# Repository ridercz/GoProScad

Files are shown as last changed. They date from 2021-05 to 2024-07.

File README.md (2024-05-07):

# GoPro Mounts OpenSCAD Library

This library contains modules to include accessory mounts and screw handles compatible with GoPro. This type of mounts and holders seems to be kind of standard nowadays. You can use it to mount anything to anything, with one or both parts of the joint 3D printed. To join the parts together a simple M5 screw and nut (square nut, preferrably) is required.

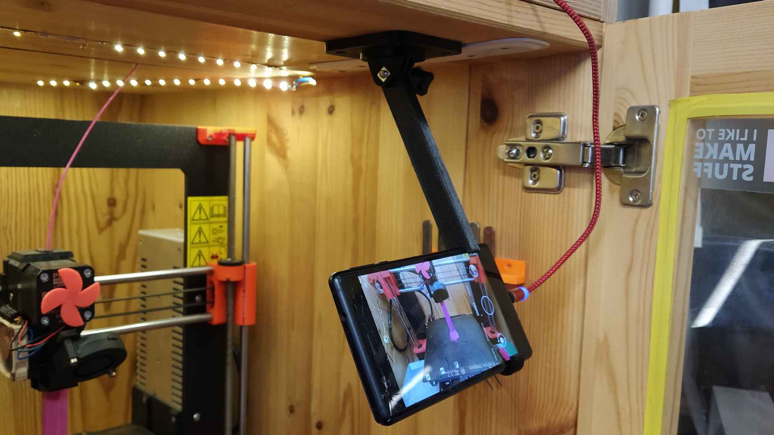
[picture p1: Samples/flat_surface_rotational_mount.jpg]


The above photograph shows example models _flat surface rotational mount_ and _phone holder_ for timelapse photography during 3D print.

## Samples

In the `Samples` folder there is bunch of useful models, showcasing the library functions:

* [`extension_arm.scad`](Samples/extension_arm.scad) is simple M-F extension arm with variable length.
* [`flat_surface_rotational_mount.scad`](Samples/flat_surface_rotational_mount.scad) is two-part mount that can be screwed to flat surface and offers rotational mount.
* [`phone_holder.scad`](Samples/phone_holder.scad) is a parametric holder for any cell phone, with or without cover.
* [`screw_handle.scad`](Samples/screw_handle.scad) is just a simple handles model for M5x50 screws with hex- and flat heads.
* [`tripod_mount.scad`](Samples/tripod_mount.scad) is a mount for tripods with conical square adapters.

## Modules

The following modules are available. All have sensible defaults and in most cases you won't need to use any arguments, maybe except `center`.

### gopro_mount_m

Will create the male mount connector (the one usually found on the camera or camera case).

    gopro_mount_m(
        base_height = 3, 
        base_width = 20, 
        leg_height = 17, 
        center = false)

* `base_height`, `base_width` = dimensions of the base plate, depth is always 9.5.
* `leg_height` = height of the legs. Do not change unless you really have to.
* `center` = if set to `false` (default), the model will be centered on X and will begin on Y and Z origins. If set to `true`, the Y will be centered on mounting axis.

### gopro_mount_f

Will create the female mount connector (the one usually found on the tripod/holder part).

    gopro_mount_f(
        base_height = 3, 
        base_width = 24, 
        leg_height = 17, 
        nut_diameter = 11.5, 
        nut_sides = 4, 
        nut_depth = 3, 
        center = false);

* `base_height`, `base_width` = dimensions of the base plate, depth is always 19 mm.
* `leg_height` = height of the legs. Do not change unless you really have to.
* `nut_diameter`, `nut_depth`, `nut_sides` = parameters of the embedded nut. Default to M5 square nut. Set `nut_depth = 0` to omit the nut guard.
* `center` = if set to `false` (default), the model will be centered on X and will begin on Y and Z origins. If set to `true`, the Y will be centered on mounting axis (which is not axis of the model itself).

### gopro_screw_handle

Will create a screw handle for M5 screw to hold the parts together. Usually, M5x50 screws are ideal.

    gopro_screw_handle(
        screw_length = 50,
        total_length = 0, 
        hex_head = true);

* `screw_length` = length of the M5 screw thread. Usually it's the nominal length (for M5x50 it's `50`). For flat and oval heads you usually need to add about 3 mm (so Mx50 with flat head would require `screw_length = 53`).
* `total_length` = total length of the handle. Set to `0` (default) to generate it automatically based on screw length.
* `hex_head` = type of screw head. If set to `true`, screw with hexagonal head is expected and the head hole will therefore have hexagonal shape. If set to `false`, other head types (usually flat) is expected. The head hole will be round and the screw hole will be slightly smaller so the threads will have something to bite into.

## Legal

* This project is created and maintained by [Michal Altair Valášek](https://www.rider.cz/).
* The code is licensed under the terms of the [MIT License](LICENSE).
* This project adheres to [No Code of Conduct](CODE_OF_CONDUCT.md). We are all adults. We accept anyone's contributions. Nothing else matters.

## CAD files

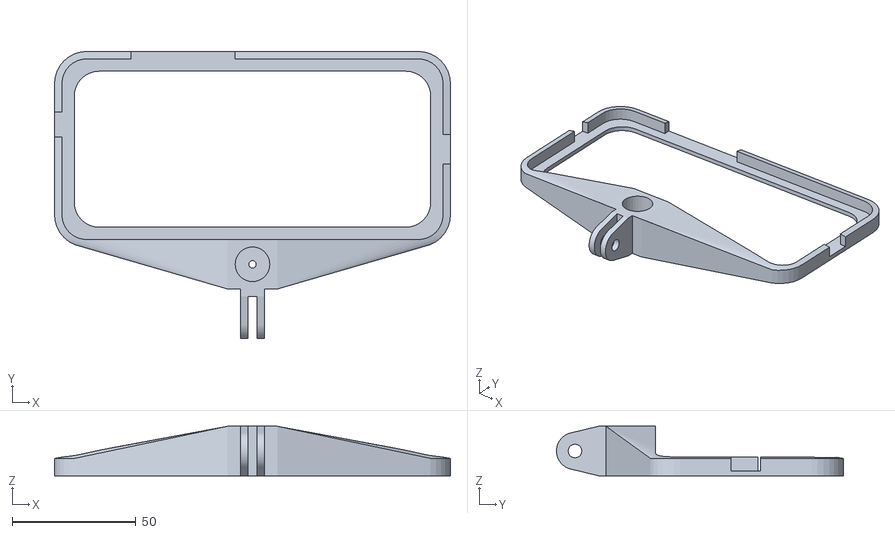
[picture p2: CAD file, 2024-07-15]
Samples/STL/horizontal_phone_holder_Xiaomi_Mi_A3.stl
160.0 x 116.0 x 20.0

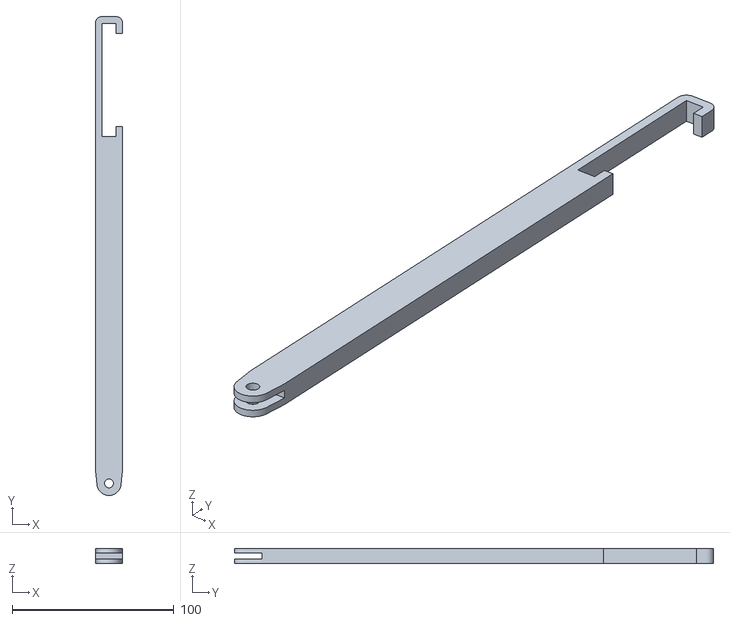
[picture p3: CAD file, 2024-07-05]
Samples/STL/phone_holder_SamsungS7.stl
17.0 x 296.5 x 9.50

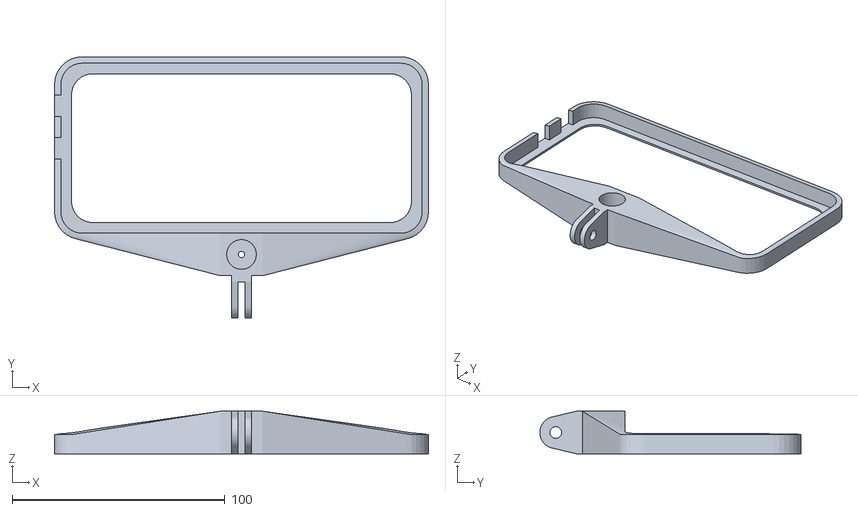
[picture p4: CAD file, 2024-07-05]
Samples/STL/horizontal_phone_holder_MotoG20.stl
176.0 x 123.0 x 20.0

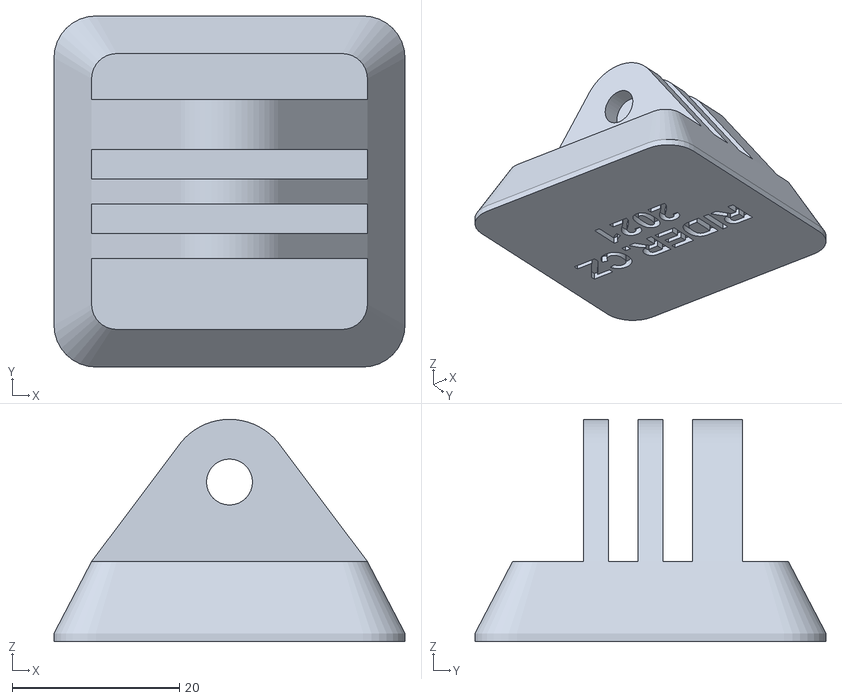
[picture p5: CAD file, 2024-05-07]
Samples/STL/tripod_mount.stl
42.0 x 42.0 x 26.6

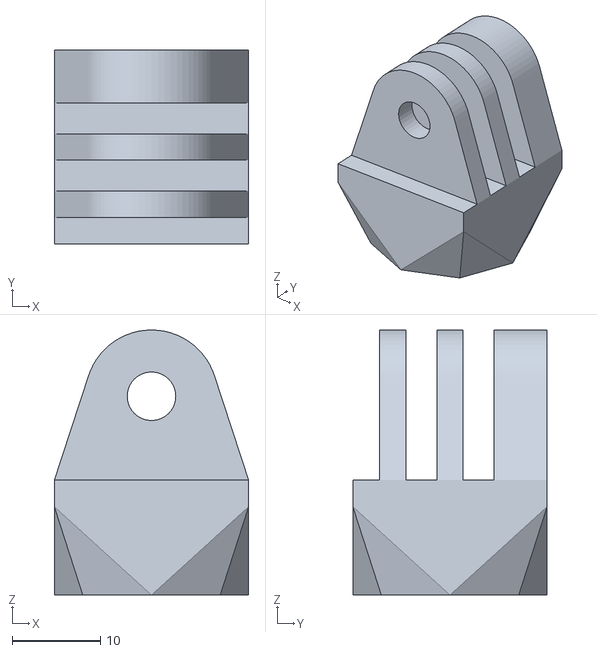
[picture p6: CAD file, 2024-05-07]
Samples/STL/mic_boom_3-8.stl
22.0 x 22.0 x 30.0

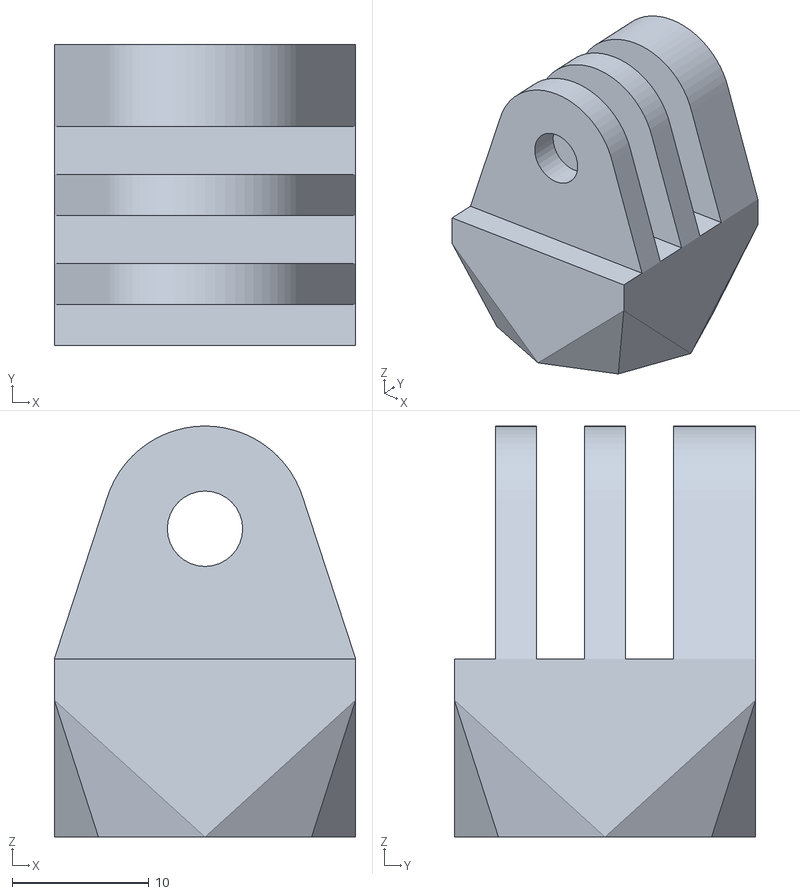
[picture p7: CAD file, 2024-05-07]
Samples/STL/mic_boom_5-8.stl
22.0 x 22.0 x 30.0

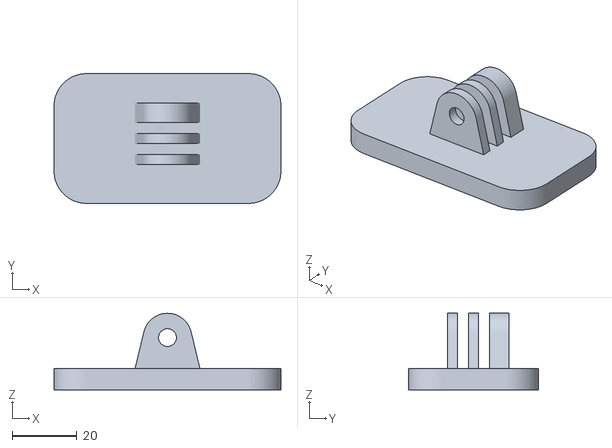
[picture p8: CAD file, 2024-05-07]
Samples/STL/magnetic_mount.stl
70.0 x 40.0 x 23.6

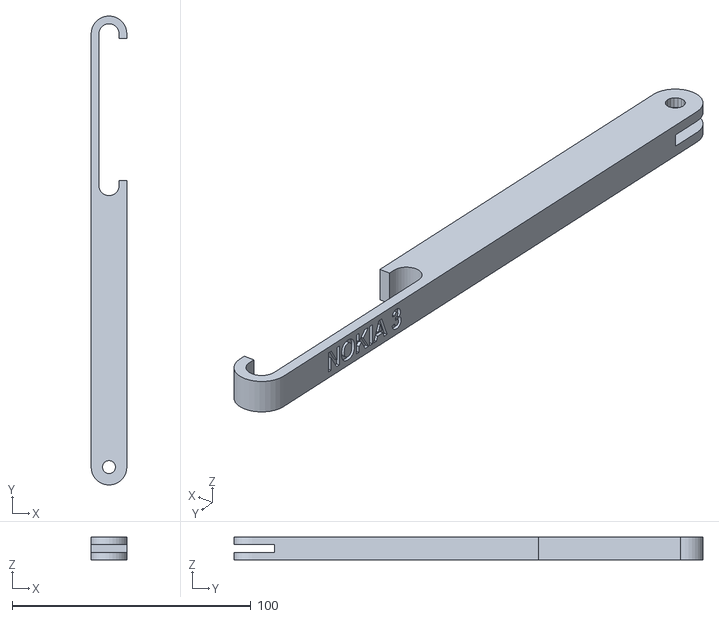
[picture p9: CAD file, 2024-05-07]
Samples/STL/phone_holder_Nokia3_long.stl
15.0 x 196.5 x 9.50

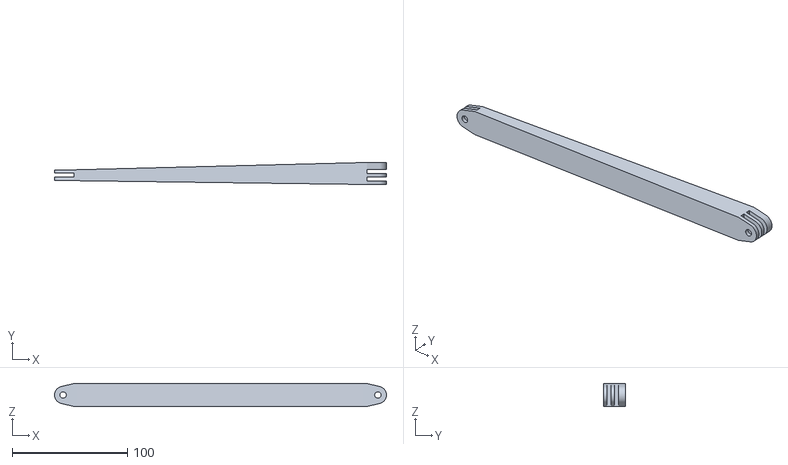
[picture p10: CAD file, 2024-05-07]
Samples/STL/extension_arm_250.stl
288.0 x 19.0 x 20.0

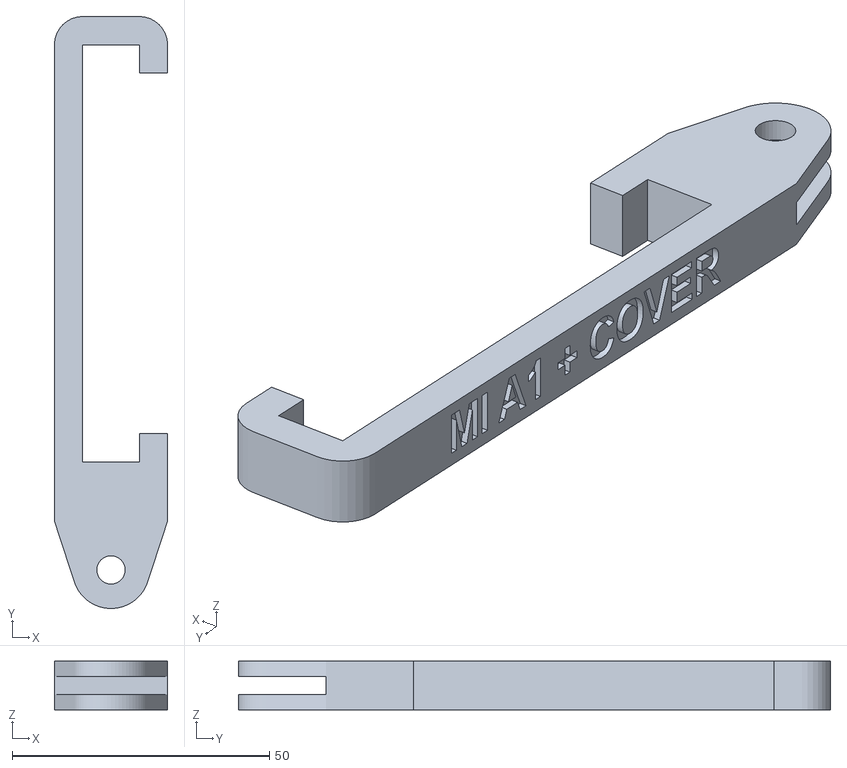
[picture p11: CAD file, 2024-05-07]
Samples/STL/phone_holder_A1.stl
22.0 x 115.0 x 9.50

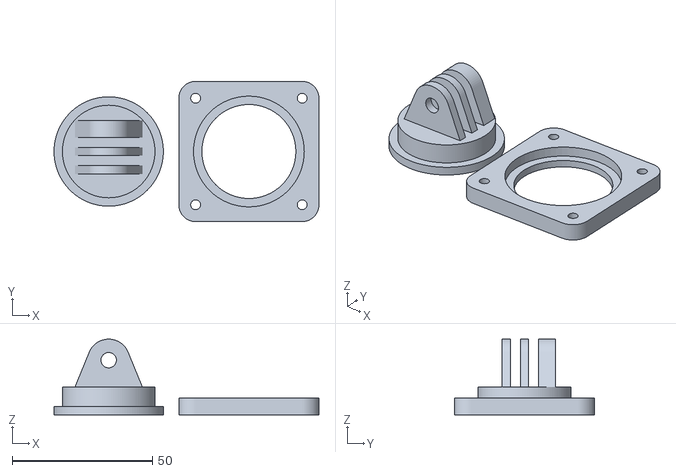
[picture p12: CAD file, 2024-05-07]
Samples/STL/flat_surface_rotational_mount.stl
94.5 x 50.0 x 27.0

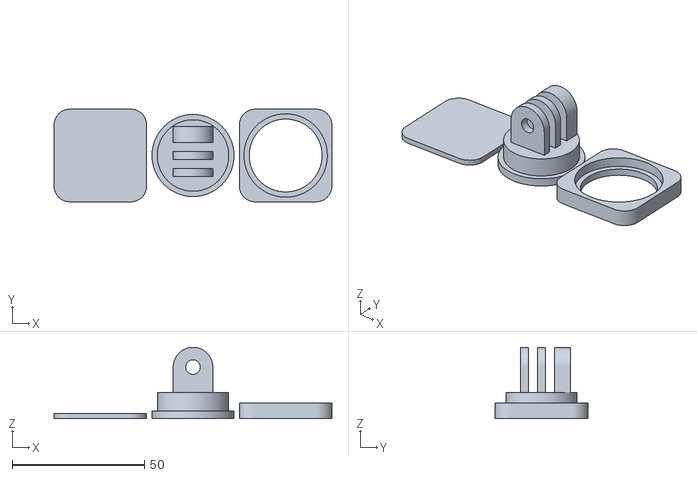
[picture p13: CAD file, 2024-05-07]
Samples/STL/flat_surface_rotational_mount_minsize.stl
105.0 x 35.0 x 27.0

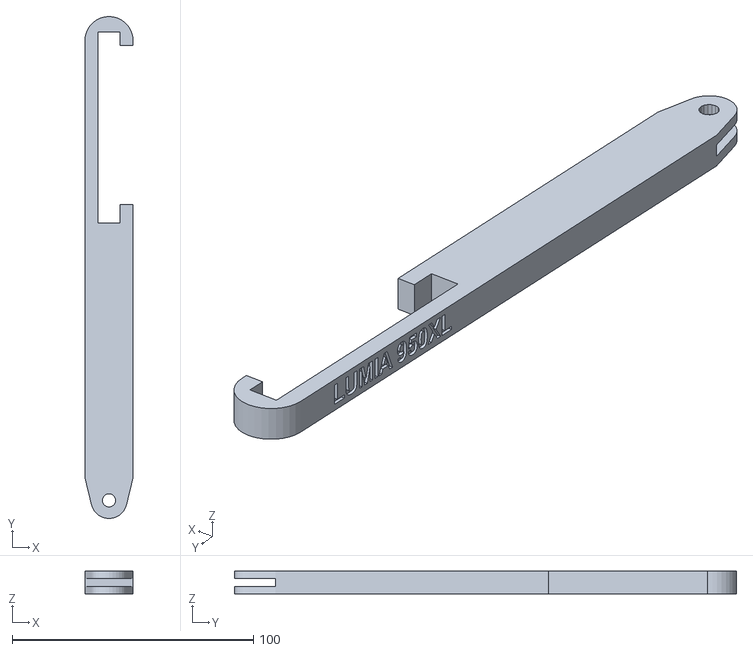
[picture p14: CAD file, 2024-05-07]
Samples/STL/phone_holder_Lumia950XL_long.stl
20.0 x 208.0 x 9.50

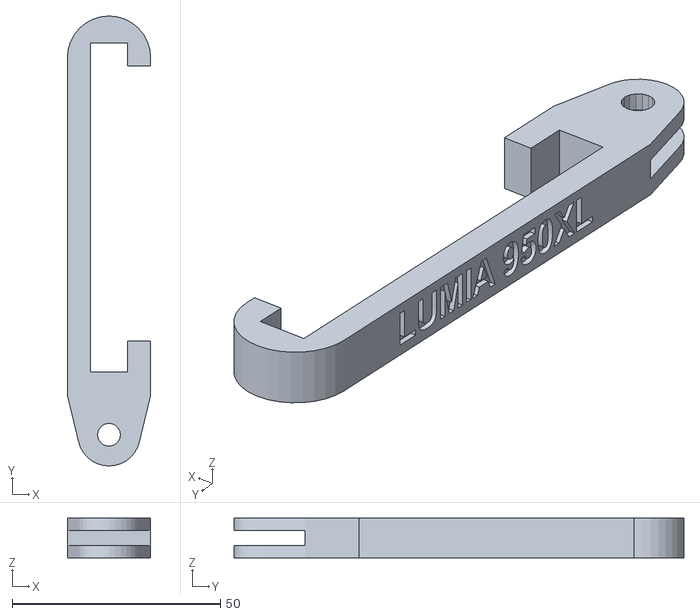
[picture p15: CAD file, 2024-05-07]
Samples/STL/phone_holder_Lumia950XL.stl
20.0 x 108.0 x 9.50

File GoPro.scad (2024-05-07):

/****************************************************************************
 * Altair's GoPro mounts library for OpenSCAD   version: 1.2.2 (2021-05-23) *
 * Copyright (c) Michal A. Valasek, 2021                                    *
 * ------------------------------------------------------------------------ *
 * www.rider.cz | www.altair.blog | github.com/ridercz/GoProScad            *
 ****************************************************************************/

// These values are fixed and defined by GoPro mount standard
__gopro_outer_diameter = 15;            // Outer diameter of the legs
__gopro_leg_width = 3;                  // Width of the legs
__gopro_slit_width = 3.5;               // Width of the slits, including tolerance
__gopro_hole_diameter = 5;              // M5
__gopro_hole_tolerance = .5;            // Print tolerance for hole
__gopro_screw_extension_length = 18;    // Length of the part of screw that sticks out
__gopro_screw_head_diameter = 9.5;      // M5
__gopro_screw_head_height = 3.5;        // M5
__gopro_wall_shaft = 1.67;              // Thickness of wall in the narrow part
__gopro_wall_head = 3;                  // Thickness of wall in the wide part
__gopro_knurl_diameter = 4;             // Diameter of knurls
__gopro_knurl_offset = -1;              // Center distance offset of knurls

module gopro_mount_f(base_height = 3, base_width = 20, leg_height = 17, nut_diameter = 11.5, nut_sides = 4, nut_depth = 3, center = false, $fudge = 1) {
    // Check arguments
    assert(base_height > 0, "Parameter base_height must be greater than zero.");
    assert(base_width >= 15, "Parameter base_width must be at least 15.");
    assert(leg_height >= 15, "Parameter leg_height must be at least 15.");
    assert(nut_sides == 4 || nut_sides == 6, "Parameter nut_sides must be either 4 or 6.");

    // Computed values
    hole_offset = leg_height - __gopro_outer_diameter / 2 + base_height;
    base_depth = __gopro_slit_width * 2 + __gopro_leg_width * 3 + nut_depth;
    center_offset_y = __gopro_leg_width * 1.5 + __gopro_slit_width;

    // Model itself
    translate(center ? [0, -center_offset_y] : [0, 0]) difference() {
        // Outer shape
        hull() {
            translate([-base_width / 2, 0]) cube([base_width, base_depth, base_height]);
            translate([0, 0, hole_offset]) rotate([-90, 0, 0]) cylinder(d = __gopro_outer_diameter, h = base_depth, $fn = 64);
        }

        // Leg slits
        for(y_offset = [__gopro_leg_width, 2 * __gopro_leg_width + __gopro_slit_width]) translate([-base_width / 2 - $fudge, y_offset, base_height]) cube([base_width + 2 * $fudge, __gopro_slit_width, leg_height]);

        // Screw + nut hole
        translate([0, -$fudge, hole_offset]) rotate([-90, 0,0]) {
            cylinder(d = __gopro_hole_diameter + __gopro_hole_tolerance, h = base_depth + 2 * $fudge, $fn = 32);
            if(nut_depth > 0) translate([0, 0, base_depth + $fudge - nut_depth]) cylinder(d = nut_diameter, h = nut_depth + $fudge, $fn = nut_sides);
        }
    }
}

module gopro_mount_m(base_height = 3, base_width = 20, leg_height = 17, center = false) {
    assert(base_height > 0, "Parameter base_height must be greater than zero.");
    assert(base_width >= 15, "Parameter base_width must be at least 15.");
    assert(leg_height >= 15, "Parameter leg_height must be at least 15.");

    // Computed values
    base_depth = __gopro_leg_width * 2 + __gopro_slit_width;
    hole_offset = [base_height + leg_height - __gopro_outer_diameter / 2, base_width / 2];

    // Model itself
    translate(center ? [0, -base_depth / 2] : [0, 0]) {
        translate([-base_width / 2, 0]) cube([base_width, __gopro_leg_width * 2 + __gopro_slit_width, base_height]);
        translate([0, __gopro_leg_width + __gopro_slit_width / 2]) rotate(90) translate([base_depth / 2, -hole_offset[1]]) rotate([0, -90, 0]) for(z_offset = [0, __gopro_leg_width + __gopro_slit_width]) translate([0, 0, z_offset]) linear_extrude(__gopro_leg_width) difference() {
            hull() {
                square([base_height, base_width]);
                translate(hole_offset) circle(d = __gopro_outer_diameter, $fn = 64);
            }
            translate(hole_offset) circle(d = __gopro_hole_diameter + __gopro_hole_tolerance, $fn = 32);
        }
    }
}

module gopro_screw_handle(screw_length = 50, total_length = 0, hex_head = true, $fudge = 1) {
    assert(screw_length > __gopro_screw_extension_length + 3, "Parameter screw_length is too short.");

    // Computed values
    screw_inner_length = screw_length - __gopro_screw_extension_length;
    screw_hole_diameter = __gopro_hole_diameter + (hex_head ? __gopro_hole_tolerance : 0);
    real_total_length = total_length > 0 ? total_length : screw_inner_length + 3 * __gopro_screw_head_height;
    handle_length = real_total_length - screw_inner_length + (hex_head ? 0 : __gopro_screw_head_height);

    difference() {
        union() {
            // Base shape
            hull() {
                cylinder(d = screw_hole_diameter + 2 * __gopro_wall_shaft, h = real_total_length, $fn = 32);
                cylinder(d = __gopro_screw_head_diameter + 2 * __gopro_wall_head, h = handle_length, $fn = 6);
            }

            // Knurls
            for(a = [0 : 60 : 359]) rotate(a) translate([__gopro_screw_head_diameter / 2 + __gopro_wall_head + __gopro_knurl_offset, 0]) {
                cylinder(d = __gopro_knurl_diameter, h = handle_length * .75, $fn = 24);
                translate([0, 0, handle_length * .75]) cylinder(d1 = __gopro_knurl_diameter, d2 = 0, h = handle_length * .25, $fn = 16);
            }
        }

        // Screw hole
        translate([0, 0, -$fudge]) cylinder(d = screw_hole_diameter, h = real_total_length + 2 * $fudge, $fn = 32);
	    translate([0, 0, -$fudge]) cylinder(d = __gopro_screw_head_diameter, h = handle_length + $fudge, $fn = hex_head ? 6 : 32);
    }
}

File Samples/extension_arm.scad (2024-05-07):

/****************************************************************************
 * GoPro mount extension arm                                                *
 * Copyright (c) Michal A. Valasek, 2021                                    *
 * ------------------------------------------------------------------------ *
 * www.rider.cz | www.altair.blog | github.com/ridercz/GoProScad            *
 ****************************************************************************/

include <../GoPro.scad>;    // https://github.com/ridercz/GoProScad

length = 250;

/* [Hidden] */
$fudge = 1;

mounts();
hull() intersection() {
    // This is kind of ugly hack and does not help performance very much.
    // But this is simple model, so screw performance :)
    mounts();
    rotate([0, 90, 0]) linear_extrude(length) square(30, center = true);
}

module mounts() {
    translate([$fudge, 0, 0]) rotate([0, -90, 0]) gopro_mount_m($fudge = $fudge, center = true);
    translate([length - $fudge, 0]) rotate([0, +90, 0]) gopro_mount_f($fudge = $fudge, center = true);
}

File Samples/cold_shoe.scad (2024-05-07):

/****************************************************************************
 * GoPro to cold shoe adapter                                               *
 * Copyright (c) Michal A. Valasek, 2022                                    *
 * ------------------------------------------------------------------------ *
 * www.rider.cz | www.altair.blog | github.com/ridercz/GoProScad            *
 ****************************************************************************/

include <../GoPro.scad>;    // https://github.com/ridercz/GoProScad
include <A2D.scad>;         // https://github.com/ridercz/A2D
assert(a2d_required([1, 6, 2]), "Please upgrade A2D library to version 1.6.2 or higher.");

/* [Cold Shoe Options] */
cold_shoe_hole_size = 20;
cold_shoe_hole_height = 3;
cold_shoe_hole_neck_width = 14;
cold_shoe_hole_neck_height = 2;

/* [Holder] */
holder_corner_radius = 3;
holder_padding = 5;
holder_base_height = 3;

/* [Hidden] */
$fn = 16;
holder_size = cold_shoe_hole_size + 2 * holder_padding;
holder_height = holder_base_height + cold_shoe_hole_height + cold_shoe_hole_neck_height;

difference() {
    // Holder outer shape
    linear_extrude(holder_height) r_square([holder_size, holder_size], holder_corner_radius, center = true);
    
    // Neck hole
    translate([-cold_shoe_hole_neck_width / 2, -holder_size / 2 - holder_padding, holder_base_height]) cube([cold_shoe_hole_neck_width, holder_size, holder_height]);

    // Shoe hole
    translate([-cold_shoe_hole_size / 2, -holder_size / 2 - holder_padding, holder_base_height]) cube([cold_shoe_hole_size, holder_size, cold_shoe_hole_height]);
}

translate([0, 0, holder_base_height]) rotate([0, 180, 90]) gopro_mount_m(base_height = holder_base_height, base_width = holder_size, center = true);

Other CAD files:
Samples/STL/cold_shoe.stl
Samples/STL/phone_holder_Nokia3.stl
Samples/STL/phone_holder_A3.stl
Samples/STL/M6_mount.stl
Samples/flat_surface_rotational_mount.scad
Samples/M6_mount.scad
Samples/STL/screw_handle_M5x50_flat.stl
Samples/STL/screw_handle_M5x50_hex.stl
Samples/horizontal_phone_holder.scad
Samples/magnetic_mount.scad
Samples/mic_boom.scad
Samples/phone_holder.scad
Samples/screw_handle.scad
Samples/tripod_mount.scad

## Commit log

2021-05-22 Initial commit.
    [GoPro.scad, flat_surface_rotational_mount.scad, flat_surface_rotational_mount.stl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]
2021-05-22 Update README with sample photo.
2021-05-22 Fix handle length for flat headed screws
    [GoPro.scad, screw_handle_M5x50_flat.stl]
2021-05-22 Update default base width to be the same for male and female.
    [GoPro.scad]
2021-05-22 Add extension arm sample.
    [extension_arm.scad, extension_arm_250.stl]
2021-12-30 Add M6 mount
    [M6_mount.scad, M6_mount.stl]
2021-12-30 Make phone holder stronger for square profile phones
    [phone_holder.scad, phone_holder_A1.stl]
2022-03-07 * Add optional base cover * Make holes optional * Make holder width configurable
    [flat_surface_rotational_mount.scad]
2022-03-07 Add minimal size version
    [flat_surface_rotational_mount_minsize.stl]
2022-03-07 Add GoPro to cold shoe adaptor.
    [cold_shoe.scad, cold_shoe.stl]
2024-05-07 Fix line ends.
    [GoPro.scad, M6_mount.scad, cold_shoe.scad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]
2024-05-07 Add universal magnetic mount.
    [magnetic_mount.scad, magnetic_mount.stl]
2024-05-07 Added mic boom adaptor
    [mic_boom.scad, mic_boom_3-8.stl, mic_boom_5-8.stl]
2024-05-07 Add tripod mount STL.
    [tripod_mount.stl]
2024-05-07 Moved STLs to separate folder
    [M6_mount.stl, cold_shoe.stl, extension_arm_250.stl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]
2024-07-05 Add horizontal phone holder sample.
    [horizontal_phone_holder.scad, horizontal_phone_holder_MotoG20.stl]
2024-07-05 Upúdate Samsung S7 phone holder sample.
    [phone_holder.scad, phone_holder_SamsungS7.stl]
2024-07-15 Add support for Xiaomi Mi A3 in horizontal phone holder
    [horizontal_phone_holder.scad, horizontal_phone_holder_Xiaomi_Mi_A3.stl]
2024-07-15 Fix name
    [horizontal_phone_holder.scad]
2024-07-15 Optimized A3 holder.
    [horizontal_phone_holder.scad, horizontal_phone_holder_Xiaomi_Mi_A3.stl]
